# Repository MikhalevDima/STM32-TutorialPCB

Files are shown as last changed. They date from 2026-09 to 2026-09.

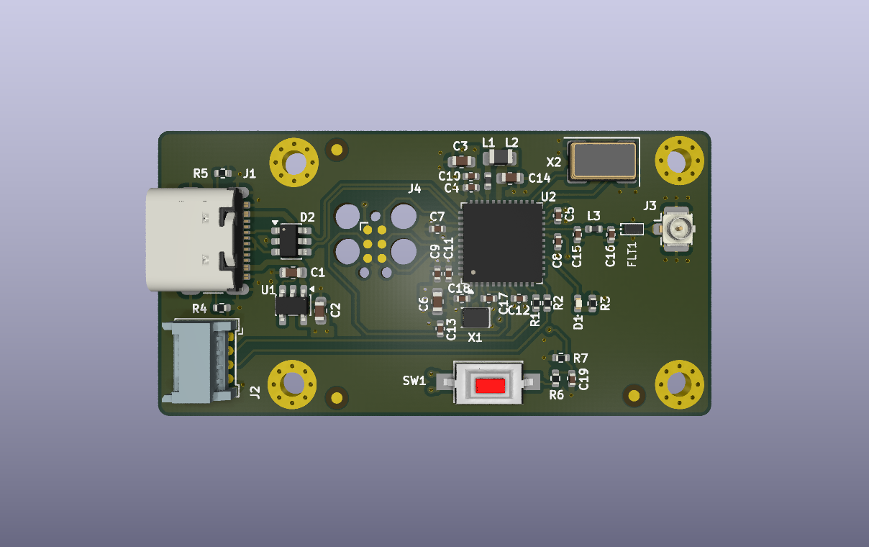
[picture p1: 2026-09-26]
docs/images/STM32-TutorialPCB_F.png

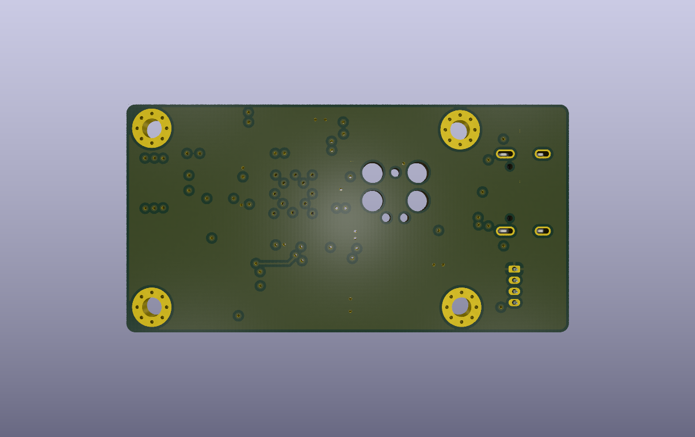
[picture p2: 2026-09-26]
docs/images/STM32-TutorialPCB_B.png

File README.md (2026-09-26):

# [MSPM0-TutorialPCB]
Двухслойная печатная плата (PCB), спроектированная в **KiCad** с использованием методологии и лучших практик инженерного канала **Phil's Lab**.
## 📸 Визуализация устройстваSTM32-TutorialPCB_F
## 🛠 Ключевые характеристики и компоненты
- **Микроконтроллер/Базовый чип:** STM32WB55CEU6.
- **Количество слоев:** 4 слоя.
- **Толщина платы / Финиш:** Разработано под стандартные 1.58 мм.
- **Интерфейсы и питание:** USB Type-C для питания и данных.
## 🚀 Что было реализовано в проекте (Инженерные навыки)
В процессе разработки этого устройства были применены следующие практики:
1. **Схемотехника и подбор компонентов:** Полный цикл отрисовки схемы, расчет номиналов обвязки (конденсаторы фильтрации, подтягивающие резисторы) на основе технической документации (Data Sheets).
2. **Интерактивная трассировка (KiCad):** Использование современных режимов трассировщика (*Shove*, *Walk Around*) для обеспечения плотного и аккуратного монтажа. С контролем импеданса 50 Ом.
3. **Цепи питания и заземления:** Организованы сплошные полигоны заземления (`GND`) для снижения помех, настроены корректные тепловые барьеры (*Thermal Reliefs*) для падов.
4. **Управление правилами проектирования (DRC):** Настроены классы цепей (*Net Classes*) и технологические зазоры (*Clearance*, *Margin*, *Courtyard*).
  ## 📁 Структура репозитория
- `/hardware` — исходные файлы проекта KiCad (`.kicad_sch`, `.kicad_pcb`).
- `/production` — итоговый пакет для завода:
  - `gerbers/` — файлы слоев в формате Gerber и файлы сверловки (`.drl`).
  - `bom/` — ведомость материалов (BOM) в формате CSV для закупки.
  - `position/` — файлы координат (`.pos`) для робота-установщика SMD.
- `/docs` — принципиальная схема в формате [PDF](docs/schematic.pdf) для быстрого просмотра (без необходимости открывать САПР).

---
*Проект разработан в учебных целях для демонстрации навыков проектирования современных печатных плат.*

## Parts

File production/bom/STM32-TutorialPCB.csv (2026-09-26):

"Reference"."Value"."Footprint"."Qty"
"C1,C2,C3,C6,C14"."4u7"."Capacitor_SMD:C_0603_1608Metric"."5"
"C4,C5,C7,C8,C9,C10,C11,C12,C13,C19"."100n"."Capacitor_SMD:C_0402_1005Metric"."10"
"C15"."0p8"."Capacitor_SMD:C_0402_1005Metric"."1"
"C16"."0p3"."Capacitor_SMD:C_0402_1005Metric"."1"
"C17,C18"."10p"."Capacitor_SMD:C_0402_1005Metric"."2"
"D1"."LED"."LED_SMD:LED_0402_1005Metric"."1"
"D2"."USBLC6-2SC6"."Package_TO_SOT_SMD:SOT-23-6"."1"
"FLT1"."DLF162500LT-5028A1"."MyShemFootprint:DLF162500LT-5028A1"."1"
"J1"."USB_C_Receptacle_USB2.0_16P"."Connector_USB:USB_C_Receptacle_GCT_USB4105-xx-A_16P_TopMnt_Horizontal"."1"
"J2"."Conn_01x04"."Connector_Molex:Molex_PicoBlade_53048-0410_1x04_P1.25mm_Horizontal"."1"
"J3"."Conn_Coaxial"."Connector_Coaxial:U.FL_Hirose_U.FL-R-SMT-1_Vertical"."1"
"L1"."10n"."Inductor_SMD:L_0402_1005Metric"."1"
"L2"."10u"."Inductor_SMD:L_0805_2012Metric"."1"
"L3"."2n7"."Inductor_SMD:L_0402_1005Metric"."1"
"R1,R2,R3,R6"."220R"."Resistor_SMD:R_0402_1005Metric"."4"
"R4,R5,R7"."5k1"."Resistor_SMD:R_0402_1005Metric"."3"
"SW1"."SW_Push"."Button_Switch_SMD:SW_SPST_CK_RS282G05A3"."1"
"U1"."MIC5365-3.3YD5"."Package_TO_SOT_SMD:TSOT-23-5"."1"
"U2"."STM32WB55CEU6"."Package_DFN_QFN:QFN-48-1EP_7x7mm_P0.5mm_EP5.6x5.6mm"."1"
"X1"."32kHz768"."Crystal:Crystal_SMD_2012-2Pin_2.0x1.2mm"."1"
"X2"."32MHz"."Crystal:Crystal_SMD_0603-4Pin_6.0x3.5mm"."1"

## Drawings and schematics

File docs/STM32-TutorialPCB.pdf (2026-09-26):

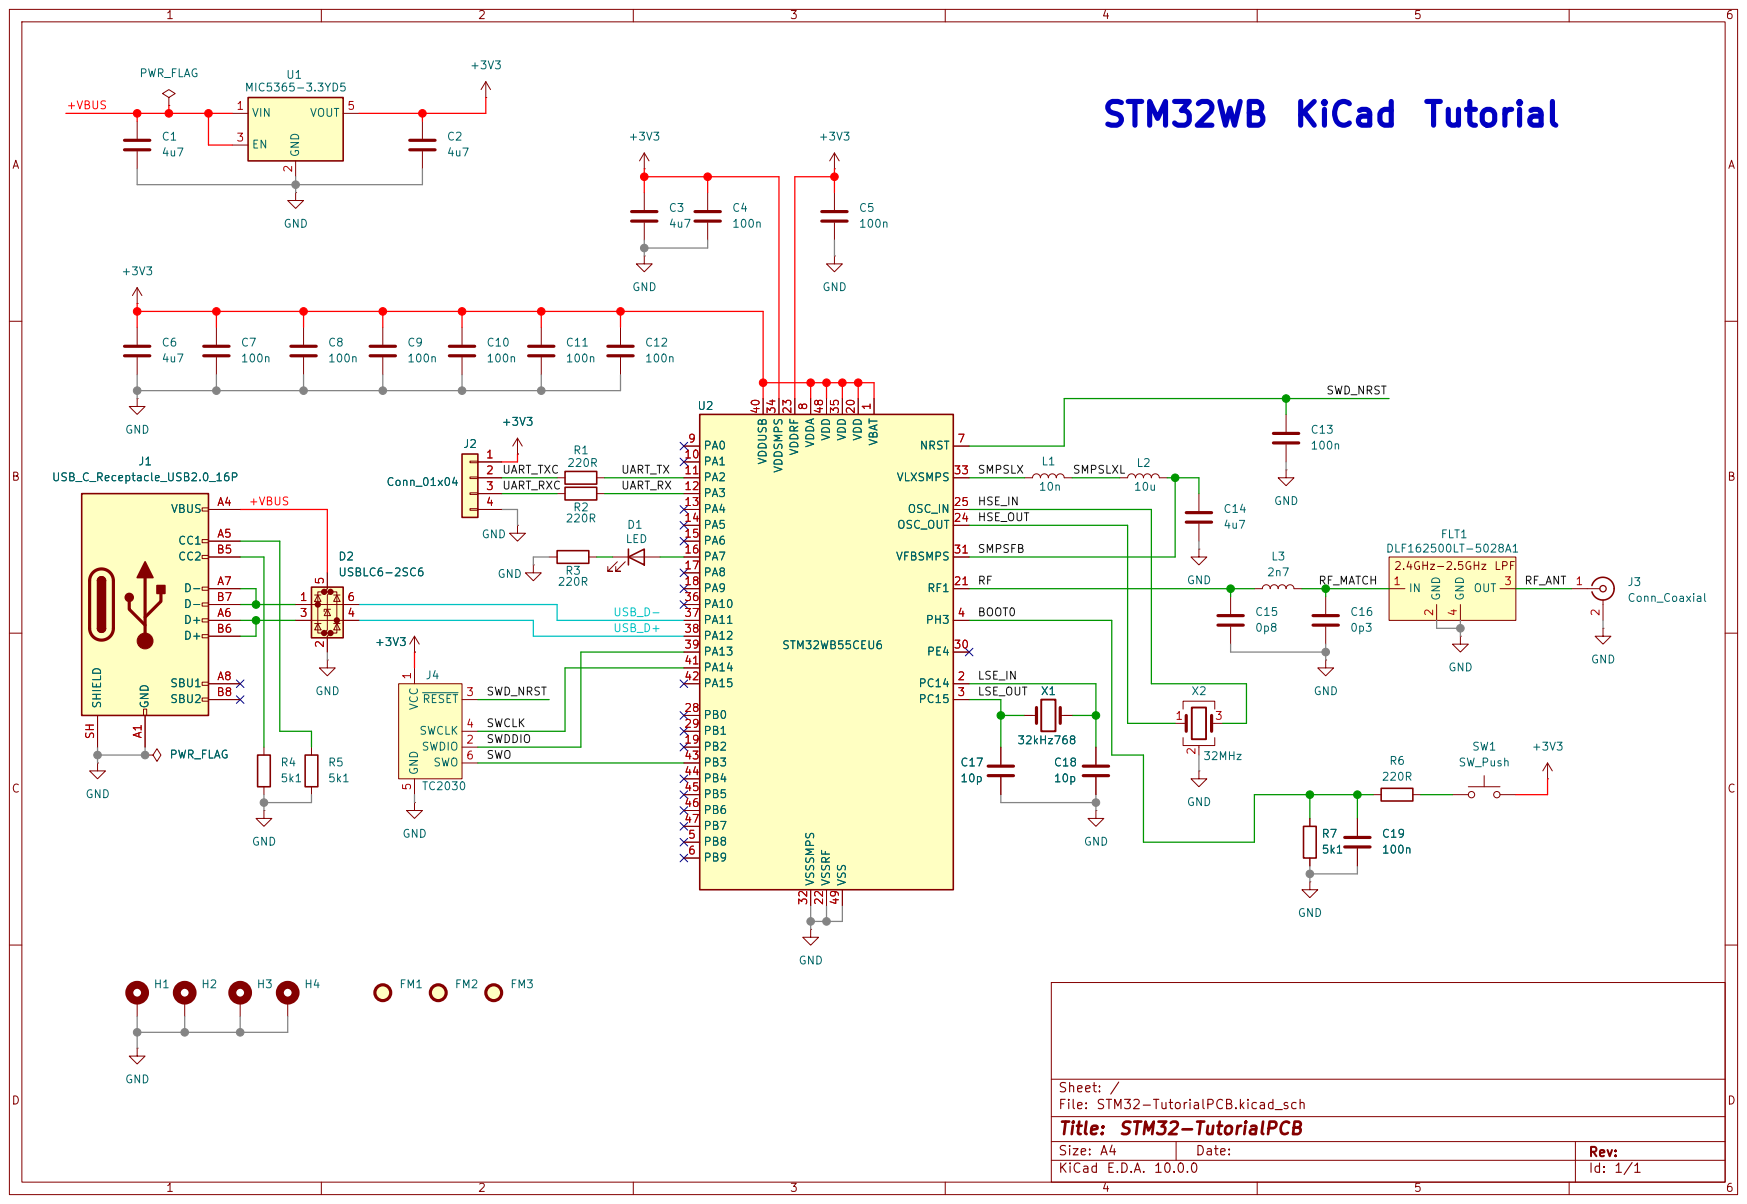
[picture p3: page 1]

BOOT0

Size: A4 | Rev:
KiCad E.D.A. 10.0.0 | Id: 1/1

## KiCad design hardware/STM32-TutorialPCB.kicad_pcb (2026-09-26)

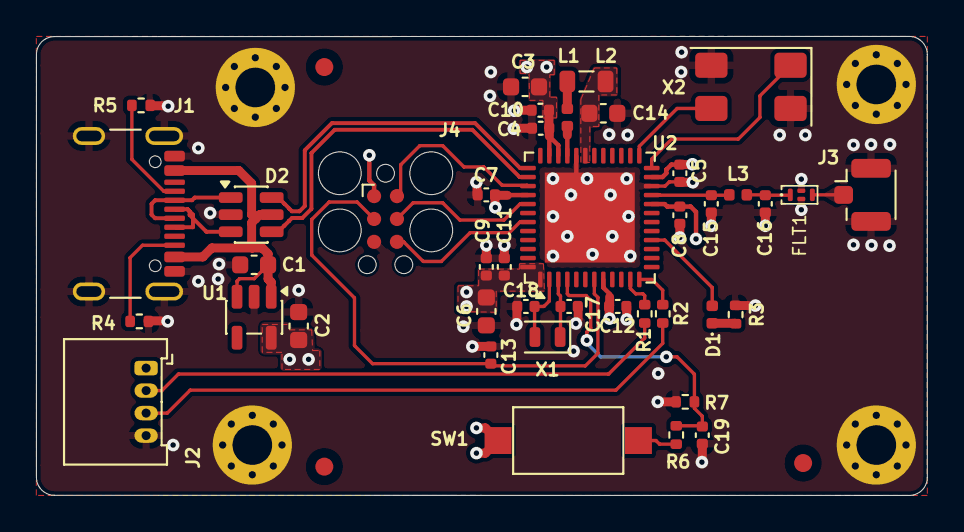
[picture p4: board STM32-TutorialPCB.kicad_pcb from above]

Board: 4 copper layers, 49.5 x 25.5 mm, 48 parts (0 on the bottom side), 31 nets.

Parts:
C1, C2, C3, C6, C14: 4u7; C_0603_1608Metric
C4, C5, C7, C8, C9, C10, C11, C12, C13, C19: 100n; C_0402_1005Metric
C15: 0p8; C_0402_1005Metric
C16: 0p3; C_0402_1005Metric
C17, C18: 10p; C_0402_1005Metric
D1: LED; LED_0402_1005Metric
D2: USBLC6-2SC6; SOT-23-6
FLT1: DLF162500LT-5028A1
FM1, FM2, FM3: Fiducial; Fiducial_1mm_Mask2mm
H1, H2, H3, H4: MountingHole_Pad; MountingHole_2.2mm_M2_Pad_Via
J1: USB_C_Receptacle_USB2.0_16P; USB_C_Receptacle_GCT_USB4105-xx-A_16P_TopMnt_Horizontal
J2: Conn_01x04; Molex_PicoBlade_53048-0410_1x04_P1.25mm_Horizontal
J3: Conn_Coaxial; U.FL_Hirose_U.FL-R-SMT-1_Vertical
J4: TC2030; Tag-Connect_TC2030-IDC-FP_2x03_P1.27mm_Vertical
L1: 10n; L_0402_1005Metric
L2: 10u; L_0805_2012Metric
L3: 2n7; L_0402_1005Metric
R1, R2, R3, R6: 220R; R_0402_1005Metric
R4, R5, R7: 5k1; R_0402_1005Metric
SW1: SW_Push; SW_SPST_CK_RS282G05A3
U1: MIC5365-3.3YD5; TSOT-23-5
U2: STM32WB55CEU6; QFN-48-1EP_7x7mm_P0.5mm_EP5.6x5.6mm
X1: 32kHz768; Crystal_SMD_2012-2Pin_2.0x1.2mm
X2: 32MHz; Crystal_SMD_0603-4Pin_6.0x3.5mm

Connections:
+3V3: C2.1, C3.1, C4.1, C5.1, C6.1, C7.1, C8.1, C9.1, C10.1, C11.1, C12.1, J2.1, J4.1 (VCC), SW1.2, U1.5 (VOUT), U2.1 (VBAT), U2.8 (VDDA), U2.20 (VDD), U2.23 (VDDRF), U2.34 (VDDSMPS), U2.35 (VDD), U2.40 (VDDUSB), U2.48 (VDD)
/+VBUS: C1.1, D2.5 (VBUS), J1.A4 (VBUS), J1.A9 (VBUS), U1.1 (VIN), U1.3 (EN)
/BOOT0: C19.1, R6.1, R7.1, U2.4 (PH3)
/HSE_IN: U2.25 (OSC_IN), X2.3
/HSE_OUT: U2.24 (OSC_OUT), X2.1
/LSE_IN: C18.1, U2.2 (PC14), X1.2
/LSE_OUT: C17.1, U2.3 (PC15), X1.1
/RF: C15.1, L3.1, U2.21 (RF1)
/RF_ANT: FLT1.3 (OUT), J3.1 (In)
/RF_MATCH: C16.1, FLT1.1 (IN), L3.2
/SMPSFB: C14.1, L2.2, U2.31 (VFBSMPS)
/SMPSLX: L1.1, U2.33 (VLXSMPS)
/SMPSLXL: L1.2, L2.1
/SWCLK: J4.4 (SWCLK), U2.41 (PA14)
/SWDDIO: J4.2 (SWDIO), U2.39 (PA13)
/SWD_NRST: C13.1, J4.3 (~RESET), U2.7 (NRST)
/SWO: J4.6 (SWO), U2.43 (PB3)
/UART_RX: R2.2, U2.12 (PA3)
/UART_RXC: J2.3, R2.1
/UART_TX: R1.2, U2.11 (PA2)
/UART_TXC: J2.2, R1.1
/USB_D+: D2.4 (I/O2), U2.38 (PA12)
/USB_D-: D2.6 (I/O1), U2.37 (PA11)
GND: C1.2, C2.2, C3.2, C4.2, C5.2, C6.2, C7.2, C8.2, C9.2, C10.2, C11.2, C12.2, C13.2, C14.2, C15.2, C16.2, C17.2, C18.2, C19.2, D2.2 (GND), FLT1.2 (GND), FLT1.4 (GND), H1.1 (1_1), H2.1 (1_1), H3.1 (1_1), H4.1 (1_1), J1.A1 (GND), J1.A12 (GND), J1.SH (SHIELD), J2.4, J3.2 (Ext), J4.5 (GND), R3.1, R4.2, R5.2, R7.2, U1.2 (GND), U2.22 (VSSRF), U2.32 (VSSSMPS), U2.49 (VSS), X2.2 (G), X2.4 (G)
unnamed: D1.2 (A), U2.16 (PA7)
unnamed: D1.1 (K), R3.2
unnamed: D2.1 (I/O1), J1.A7 (D-), J1.B7 (D-)
unnamed: D2.3 (I/O2), J1.A6 (D+), J1.B6 (D+)
unnamed: J1.A5 (CC1), R5.1
unnamed: J1.B5 (CC2), R4.1
unnamed: R6.2, SW1.1
